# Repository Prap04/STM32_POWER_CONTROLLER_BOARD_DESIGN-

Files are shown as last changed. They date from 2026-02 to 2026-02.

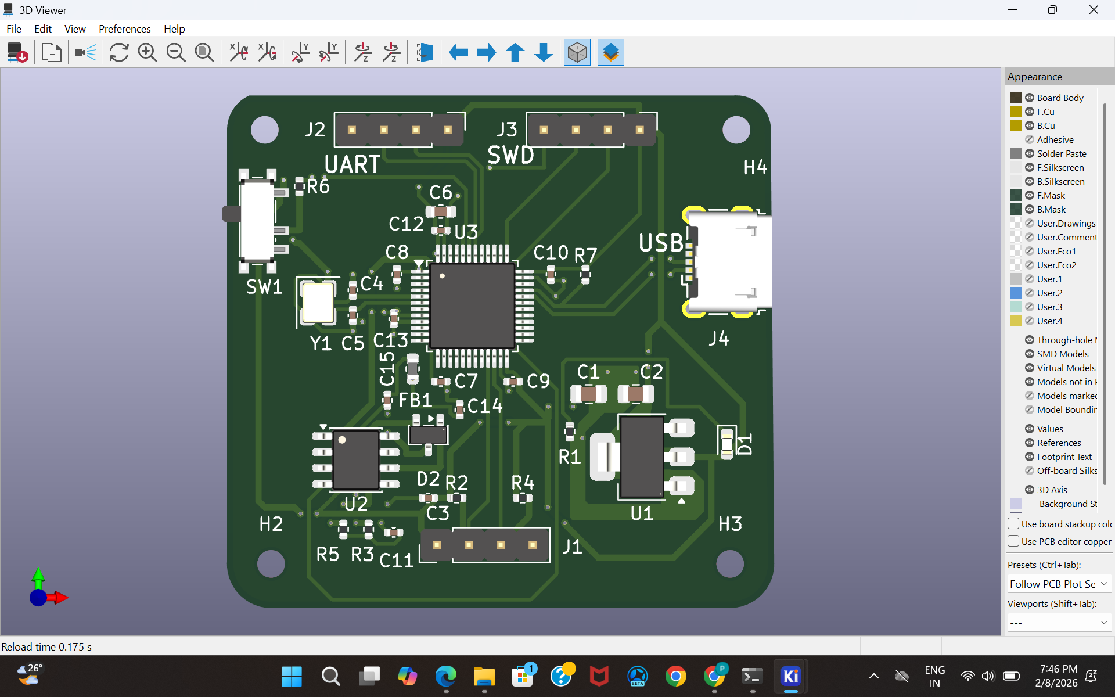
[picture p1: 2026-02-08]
Images/Screenshot (24).png

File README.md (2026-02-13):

# STM32F103 Custom Control Board (PCB Project)

This project is a **custom-made PCB (Printed Circuit Board)** built around the **STM32F103C8T6 microcontroller**.  
The goal of this project was to learn how to design a **real hardware board** instead of only using ready-made development boards.

---

## Project Goal

To design a working STM32 board that includes:

- Stable power supply
- Communication ports (CAN, UART, I2C)
- Debugging support
- A PCB that is ready for manufacturing

---

## Main Components Used

| Part | What it Does |
|---|---|
| STM32F103C8T6 | Main microcontroller (the brain of the board) |
| CAN Transceiver | Allows CAN communication (used in robotics & industry) |
| UART Header | Used for serial communication and debugging |
| I2C Pins | Used to connect sensors |
| SWD Pins (SWIO, SWCLK) | Used to upload and debug firmware |
| Capacitors | Reduce noise and stabilize power |
| Voltage Regulation | Provides safe voltage to MCU |

---

## 🔧 What I Added Beyond the Tutorial

This board was inspired by Phil’s Lab STM32 tutorial, but I added extra features:

| Feature | Why I Added It |
|---|---|
| CAN Communication | Used in industrial and robotic systems |
| Extra UART Access | Easy debugging and data output |
| I2C Support | To connect sensors |
| Better Debug Header | Easy firmware upload and testing |

---

## ⚡ Power Design (Simple Explanation)

- Small capacitors placed near MCU to reduce noise
- Bigger capacitors used to keep voltage stable
- Ground plane used to make signals cleaner

---

## 🧩 PCB Design Steps I Followed

1. Created the schematic (circuit diagram)
2. Chose the components
3. Placed components on PCB
4. Checked 3D view to see board shape
5. Routed connections
6. Ran DRC (error check)
7. Generated Gerber files
8. Prepared BOM list

---

## 🧪 How the Board Can Be Tested

If powering the board for the first time:

1. Check voltage using multimeter
2. Check clock signal
3. Upload firmware using ST-Link and SWD pins
4. Test UART communication on PC
5. Check I2C sensor connection
6. Test CAN communication

---

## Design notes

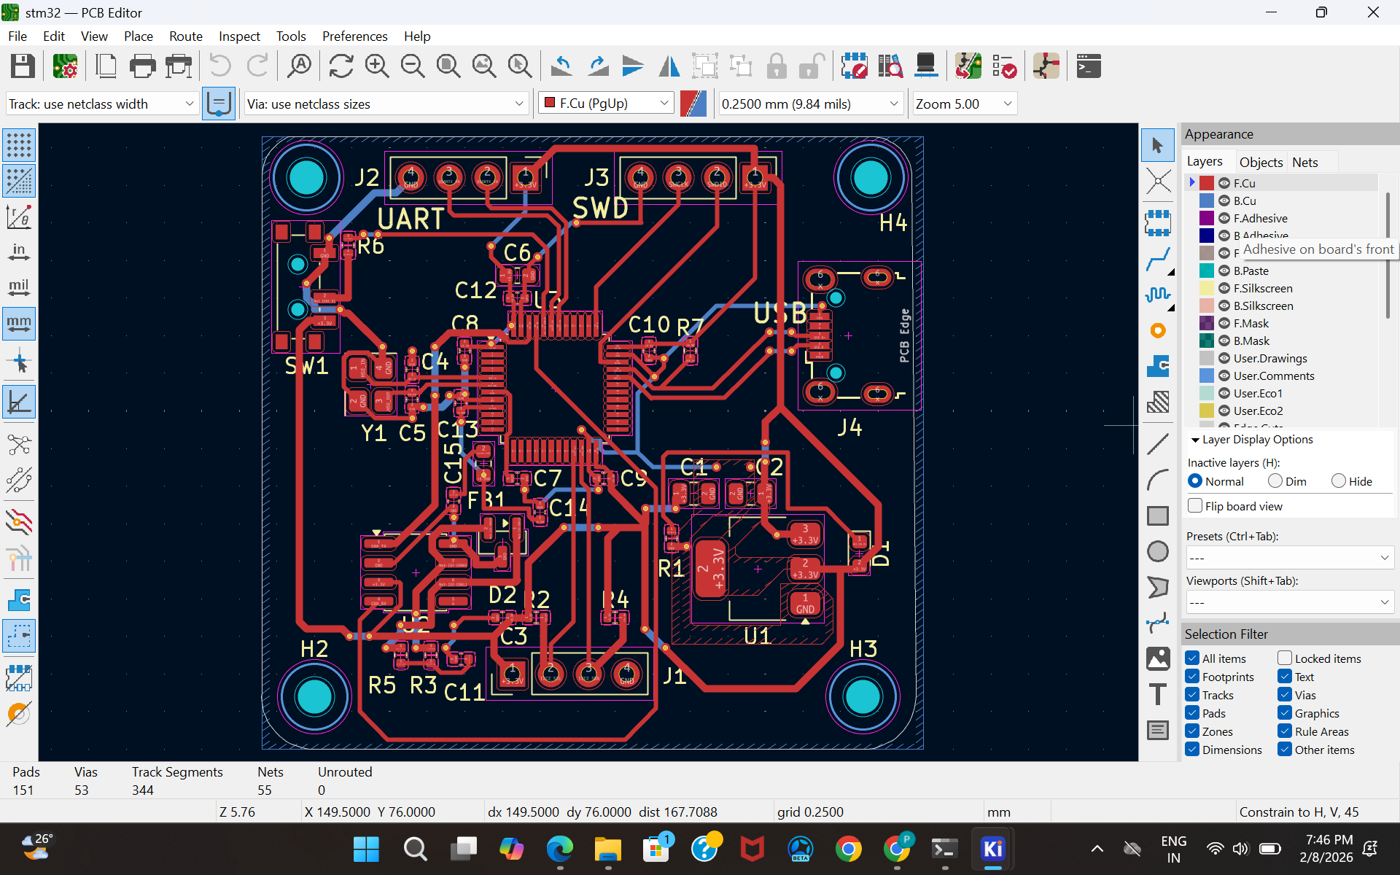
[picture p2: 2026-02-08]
Images/Screenshot (23).png

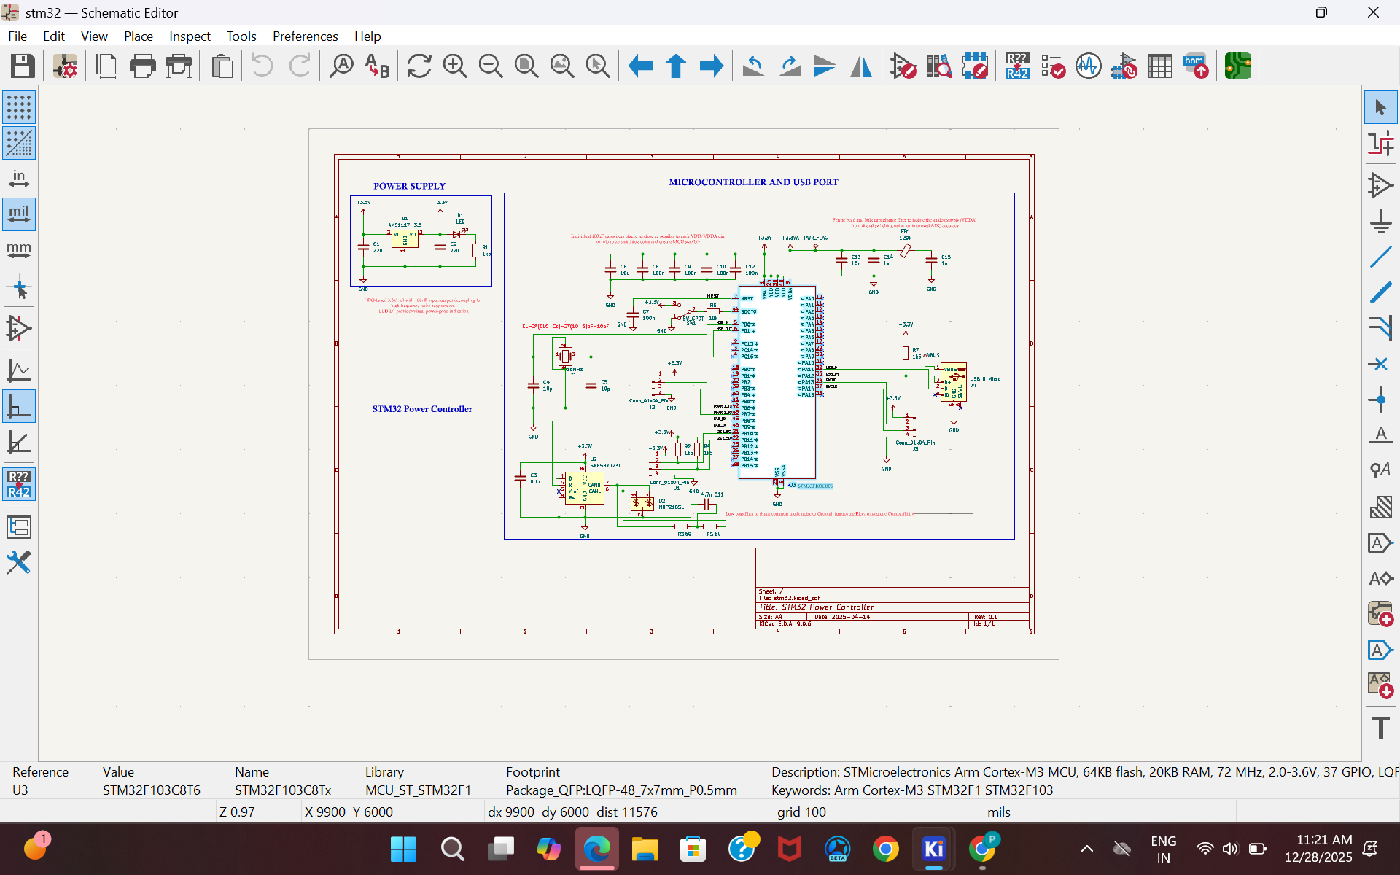
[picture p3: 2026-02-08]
Images/Screenshot (3).png

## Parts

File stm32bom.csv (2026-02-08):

Reference | Qty | Value | DNP | Exclude from BOM | Exclude from Board | Footprint | Datasheet
C1,C2 | 2 | 22u |  |  |  | Capacitor_SMD:C_0805_2012Metric | ~
C3 | 1 | 0.1u |  |  |  | Capacitor_SMD:C_0402_1005Metric | ~
C4,C5 | 2 | 10p |  |  |  | Capacitor_SMD:C_0402_1005Metric | ~
C6 | 1 | 10u |  |  |  | Capacitor_SMD:C_0603_1608Metric | ~
C7,C8,C9,C10,C12 | 5 | 100n |  |  |  | Capacitor_SMD:C_0402_1005Metric | ~
C11 | 1 | 4.7n |  |  |  | Capacitor_SMD:C_0402_1005Metric | ~
C13 | 1 | 10n |  |  |  | Capacitor_SMD:C_0402_1005Metric | ~
C14,C15 | 2 | 1u |  |  |  | Capacitor_SMD:C_0402_1005Metric | ~
D1 | 1 | LED |  |  |  | LED_SMD:LED_0603_1608Metric | ~
D2 | 1 | NUP2105L |  |  |  | Package_TO_SOT_SMD:SOT-23 | https://www.onsemi.com/pub_link/Collateral/NUP2105L-D.PDF
FB1 | 1 | 120R |  |  |  | Inductor_SMD:L_0603_1608Metric | ~
H1,H2,H3,H4 | 4 | MountingHole |  | Excluded from BOM |  | MountingHole:MountingHole_2.2mm_M2 | ~
J1,J2,J3 | 3 | Conn_01x04_Pin |  |  |  | Connector_PinHeader_2.54mm:PinHeader_1x04_P2.54mm_Vertical | ~
J4 | 1 | USB_B_Micro |  |  |  | Connector_USB:USB_Micro-B_Wuerth_629105150521 | ~
R1,R2,R4,R7 | 4 | 1k5 |  |  |  | Resistor_SMD:R_0402_1005Metric | ~
R3,R5 | 2 | 60 |  |  |  | Resistor_SMD:R_0402_1005Metric | ~
R6 | 1 | 10k |  |  |  | Resistor_SMD:R_0402_1005Metric | ~
SW1 | 1 | SW_SPDT |  |  |  | Button_Switch_SMD:SW_SPDT_PCM12 | ~
U1 | 1 | AMS1117-3.3 |  |  |  | Package_TO_SOT_SMD:SOT-223-3_TabPin2 | http://www.advanced-monolithic.com/pdf/ds1117.pdf
U2 | 1 | SN65HVD230 |  |  |  | Package_SO:SOIC-8_3.9x4.9mm_P1.27mm | http://www.ti.com/lit/ds/symlink/sn65hvd230.pdf
U3 | 1 | STM32F103C8T6 |  |  |  | Package_QFP:LQFP-48_7x7mm_P0.5mm | https://www.st.com/resource/en/datasheet/stm32f103c8.pdf
Y1 | 1 | 16MHz |  |  |  | Crystal:Crystal_SMD_3225-4Pin_3.2x2.5mm | ~

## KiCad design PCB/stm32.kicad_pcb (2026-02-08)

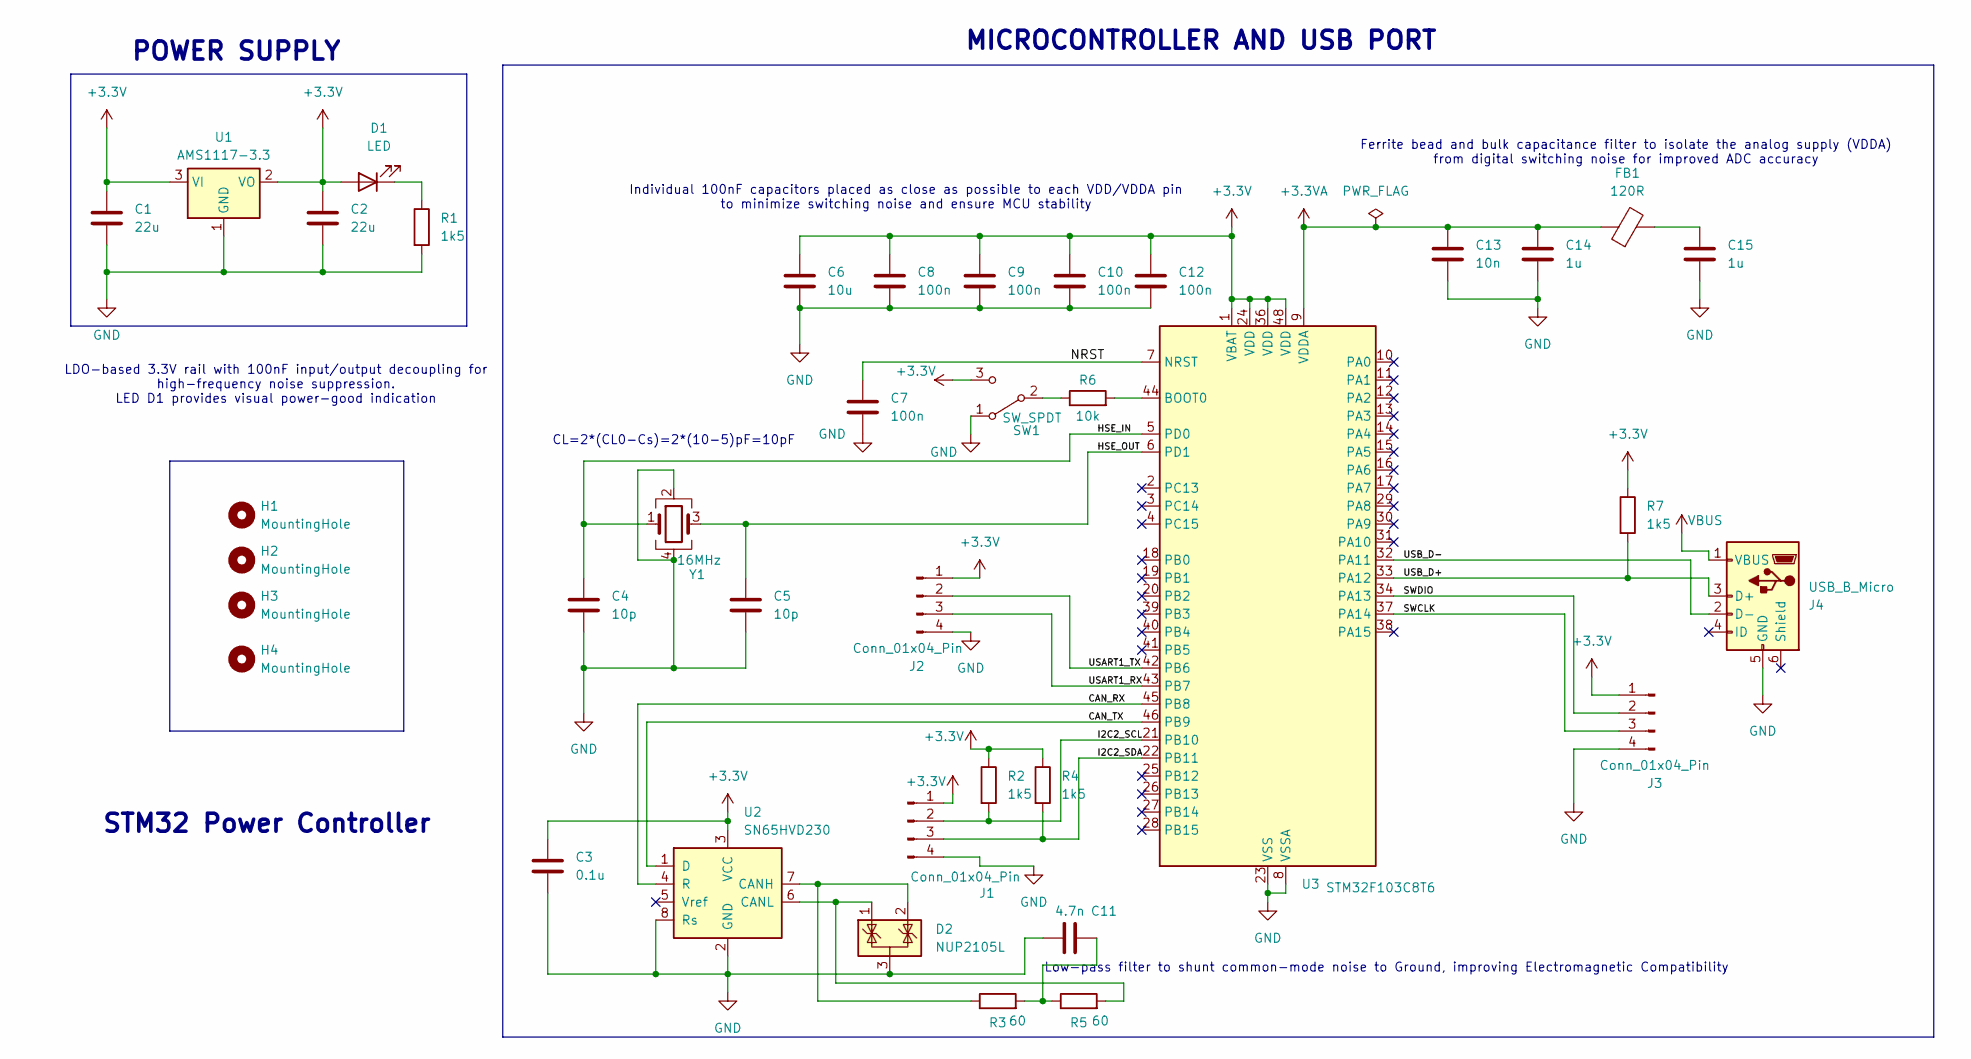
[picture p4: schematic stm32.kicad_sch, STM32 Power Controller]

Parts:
C1, C2: 22u; C_0805_2012Metric
C3: 0.1u; C_0402_1005Metric
C4, C5: 10p; C_0402_1005Metric
C6: 10u; C_0603_1608Metric
C7, C8, C9, C10, C12: 100n; C_0402_1005Metric
C11: 4.7n; C_0402_1005Metric
C13: 10n; C_0402_1005Metric
C14, C15: 1u; C_0402_1005Metric
D1: LED; LED_0603_1608Metric
D2: NUP2105L; SOT-23
FB1: 120R; L_0603_1608Metric
H1, H2, H3, H4: MountingHole; MountingHole_2.2mm_M2
J1, J2, J3: Conn_01x04_Pin; PinHeader_1x04_P2.54mm_Vertical
J4: USB_B_Micro; USB_Micro-B_Wuerth_629105150521
R1, R2, R4, R7: 1k5; R_0402_1005Metric
R3, R5: 60; R_0402_1005Metric
R6: 10k; R_0402_1005Metric
SW1: SW_SPDT; SW_SPDT_PCM12
U1: AMS1117-3.3; SOT-223-3_TabPin2
U2: SN65HVD230; SOIC-8_3.9x4.9mm_P1.27mm
U3: STM32F103C8T6; LQFP-48_7x7mm_P0.5mm
Y1: 16MHz; Crystal_SMD_3225-4Pin_3.2x2.5mm

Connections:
+3.3V: C1.1, C2.1, C3.1, C6.1, C8.1, C9.1, C10.1, C12.1, D1.2 (A), J1.1, J2.1, J3.1, R2.1, R4.1, R7.1, SW1.3 (C), U1.2 (VO), U1.3 (VI), U2.3 (VCC), U3.1 (VBAT), U3.24 (VDD), U3.36 (VDD), U3.48 (VDD)
+3.3VA: C13.1, C14.1, FB1.1, U3.9 (VDDA)
/CAN_RX: U2.4 (R), U3.45 (PB8)
/CAN_TX: U2.1 (D), U3.46 (PB9)
/HSE_IN: C4.1, U3.5 (PD0), Y1.1
/HSE_OUT: C5.1, U3.6 (PD1), Y1.3
/I2C2_SCL: J1.2, R2.2, U3.21 (PB10)
/I2C2_SDA: J1.3, R4.2, U3.22 (PB11)
/NRST: C7.1, U3.7 (NRST)
/SWCLK: J3.3, U3.37 (PA14)
/SWDIO: J3.2, U3.34 (PA13)
/USART1_RX: J2.3, U3.43 (PB7)
/USART1_TX: J2.2, U3.42 (PB6)
/USB_D+: J4.3 (D+), R7.2, U3.33 (PA12)
/USB_D-: J4.2 (D-), U3.32 (PA11)
GND: C1.2, C2.2, C3.2, C4.2, C5.2, C6.2, C7.2, C8.2, C9.2, C10.2, C11.1, C12.2, C13.2, C14.2, C15.2, D2.3 (A), J1.4, J2.4, J3.4, J4.5 (GND), R1.2, SW1.1 (A), U1.1 (GND), U2.2 (GND), U2.8 (Rs), U3.8 (VSSA), U3.23 (VSS), U3.35 (VSS), U3.47 (VSS), Y1.2, Y1.4
unnamed: C11.2, R3.2, R5.1
unnamed: C15.1, FB1.2
unnamed: D1.1 (K), R1.1
unnamed: R6.1, SW1.2 (B)
unnamed: D2.2 (K), R3.1, U2.7 (CANH)
unnamed: D2.1 (K), R5.2, U2.6 (CANL)
unnamed: R6.2, U3.44 (BOOT0)
VBUS: J4.1 (VBUS)

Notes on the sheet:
CL=2*(CL0-Cs)=2*(10-5)pF=10pF
MICROCONTROLLER AND USB PORT
Low-pass filter to shunt common-mode noise to Ground, improving Electromagnetic Compatibility
Ferrite bead and bulk capacitance filter to isolate the analog supply (VDDA) from digital switching noise for improved ADC accuracy
Individual 100nF capacitors placed as close as possible to each VDD/VDDA pin to minimize switching noise and ensure MCU stability
STM32 Power Controller
LDO-based 3.3V rail with 100nF input/output decoupling for high-frequency noise suppression. LED D1 provides visual power-good indication
POWER SUPPLY

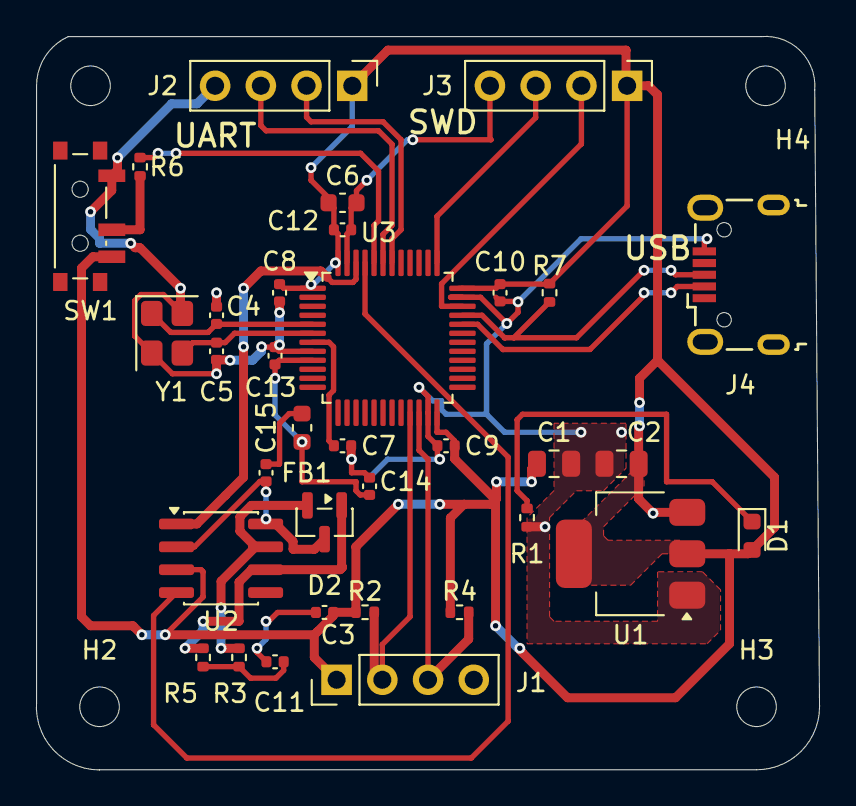
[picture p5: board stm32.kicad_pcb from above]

Board: 2 copper layers, 43.5 x 40.7 mm, 38 parts (0 on the bottom side), 23 nets.
